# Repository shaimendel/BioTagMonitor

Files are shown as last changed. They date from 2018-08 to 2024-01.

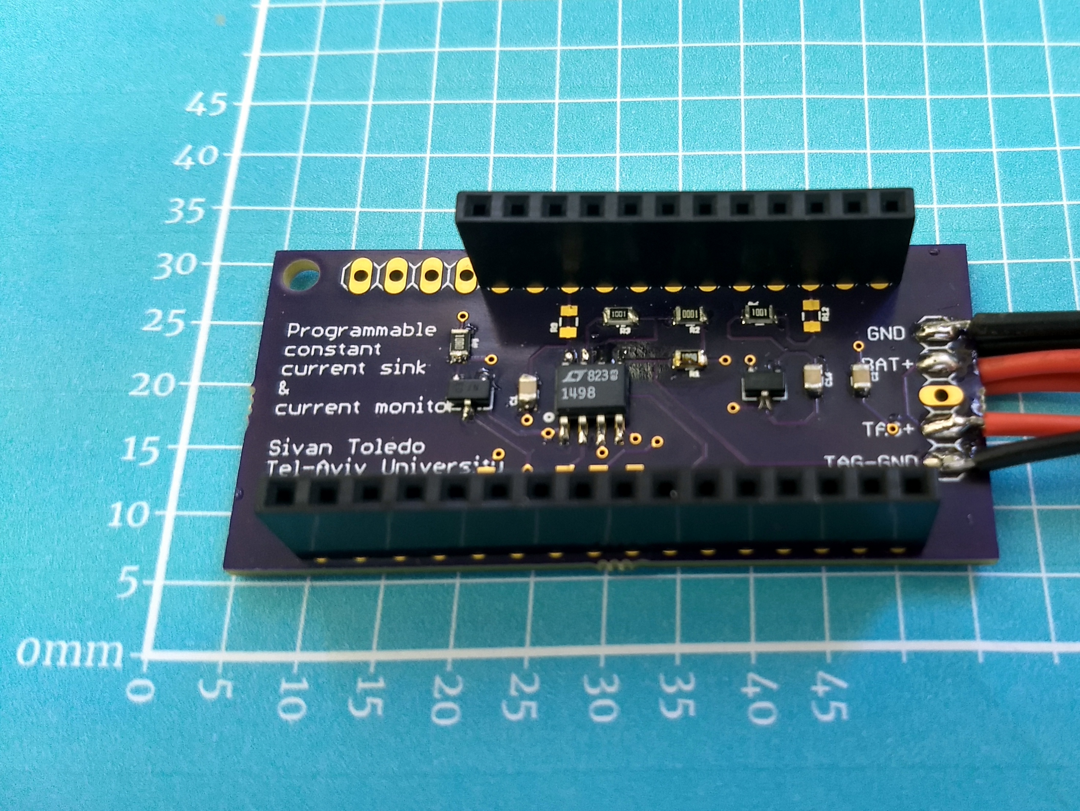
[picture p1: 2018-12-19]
Paper/2018-11-28 09.57.43.jpg

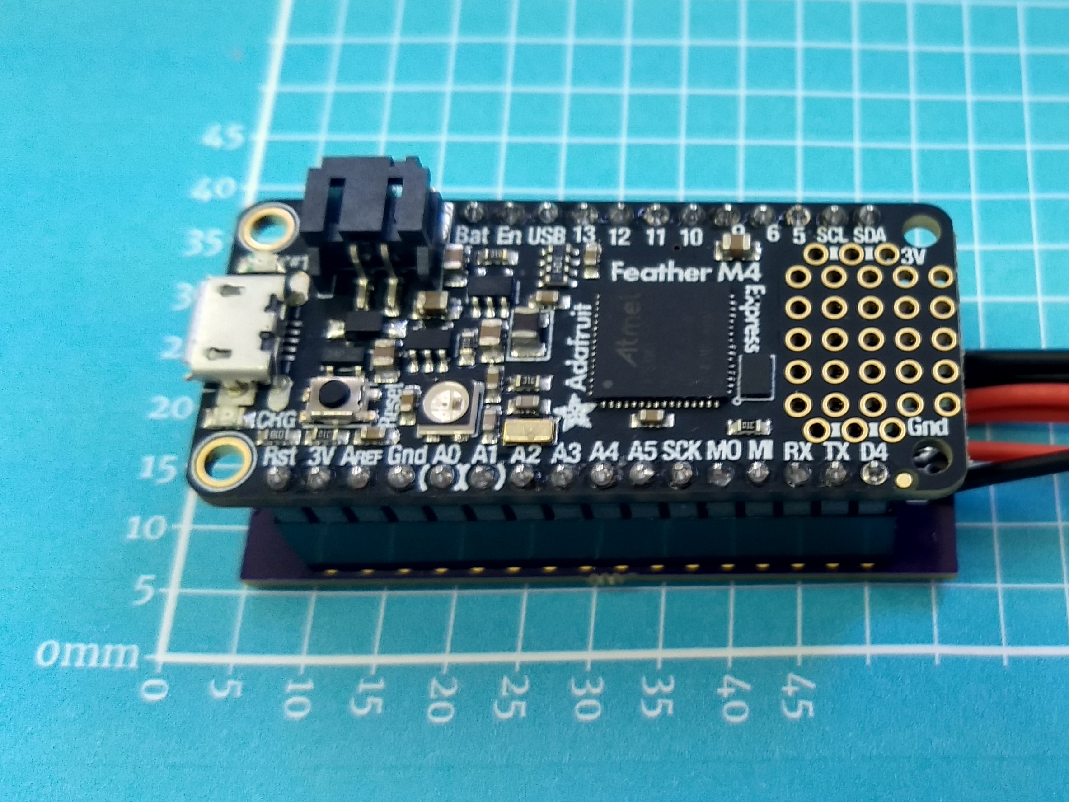
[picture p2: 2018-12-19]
Paper/2018-11-28 09.58.49.jpg

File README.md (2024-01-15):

# Software, Firmware, and Hardware for a Battery Characterization System
Biological tags are very popular in the field of animal behaviour research.
These tags developers have to deal with numerous problems, both in hardware and software.
One of the problems is to choose the correct battery to put within the tag itself: the battery should be lightweight, to last long, to cope with different weather conditions, etc.
Until now, the setup and procedure of comparing different batteries performance included:
- A mocked tag: A dedicated circuit that used the battery in the same way the tag does
- The battery itself
- Scope and other expensive equipment to measure the voltage and current along time

This procedure is long, expensive and uncomfortable.
This project concentrates on biological tags that are put on birds, these tags send a short pulse (8-10ms) of location every ~1 second.

## Goal
This project implements an arduino and PC software that communicate with each other and make the entire procedure very easy, cheap and quick.
The project contains:
- Various arduino softwares for different needs
- A PC software (C#) that operates the arduino and logs the measurements
- A PC software (Python) for visualization

## Content

### Visualization
- createData.py: Creates a mock log file with mocked measurements
- visualizeData.py: Measurements visualization utility

### Measure
The C# project that operates the arduino, both for tag simulation and also with real tags.
In order to compile Measure.csproj to mono: 
- cd to Measure.csproj folder
- xbuild /p:TargetFrameworkVersion="v4.5"

#### AutoMeasureGraphMin
Arduino software to measure bio tags.
This software communicates with the PC software and sends the measurements to it.
Supports 2 modes:
- Simulation: The sofware simulates tag behaviour and measures the battery performance in pulses along time
- Real tag: Measurement of real tag pulses. This mode contains a pulse identification algorithm, becuase the tag itself produces the pulses.

#### AutoMeasureGraphStart
Arduino software to measure bio tags in a situation the tag fails to start.
This software records measurements as soon as it identifies an activity in the tag and sends it to the PC software

#### PCB
Circuit and printed-circut board design for the add-on analog board. These are Eagle 6.6 files. The "relabeled" schmatics is cleaned up a bit for clarity. It also does not include 0-Ohm resistors and jumper traces that are included in the original design to allow patching the board. 

#### Simulation
LTSpice simulation model for the analysis of the reservoir cap and its limiter resistor.

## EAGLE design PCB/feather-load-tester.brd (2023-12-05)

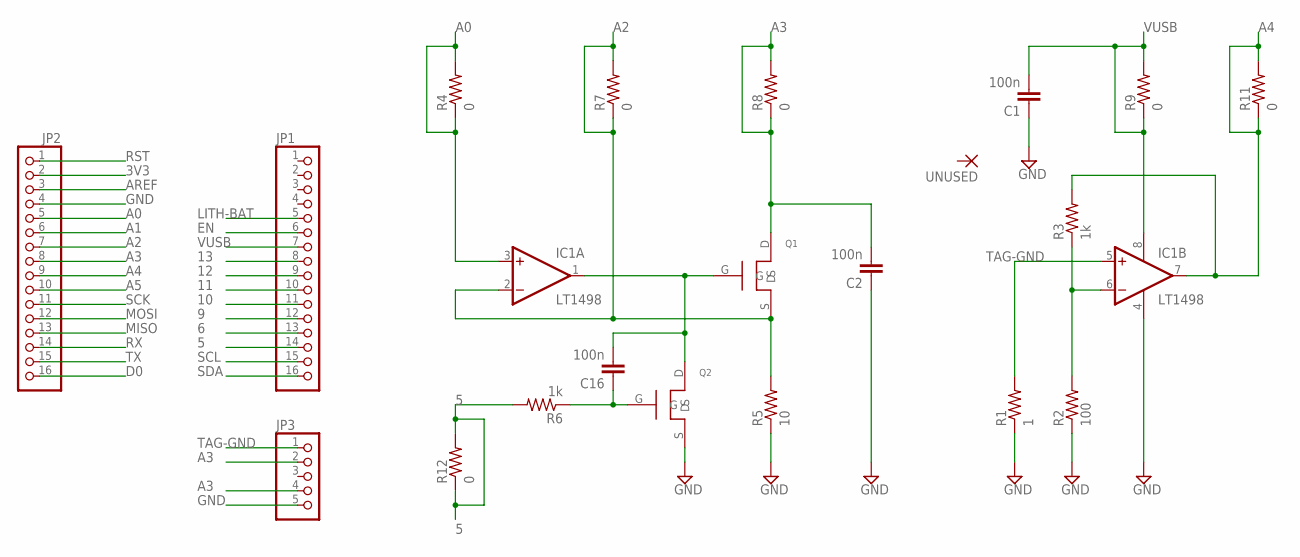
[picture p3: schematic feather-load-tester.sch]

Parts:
C1, C2, C16: 100n; 0805-CAP
IC1: LT1498; SO08
JP1, JP2: PINHD-1X16; 1X16
JP3: PINHD-1X5; 1X05
Q1, Q2: NMOSFET_SC59; SC59
R1: 1; 0805
R2: 100; 0805
R3, R6: 1k; 0805
R4, R7, R8, R9, R11, R12: 0; 0805
R5: 10; 0805
UNUSED: SMD2; SMD1,27-2,54

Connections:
3V3: JP2.2
5: JP1.14, R6.2, R12.1, R12.2
6: JP1.13
9: JP1.12
10: JP1.11
11: JP1.10
12: JP1.9
13: JP1.8
A0: IC1.3 (+IN), JP2.5, R4.1, R4.2
A1: JP2.6
A2: IC1.2 (-IN), JP2.7, Q1.S, R5.2, R7.1, R7.2
A3: C2.2, JP2.8, JP3.2, JP3.4, Q1.D, R8.1, R8.2
A4: IC1.7 (OUT), JP2.9, R3.2, R11.1, R11.2
A5: JP2.10
AREF: JP2.3
D0: JP2.16
EN: JP1.6
GND: C1.1, C2.1, IC1.4 (V-), JP2.4, JP3.5, Q2.S, R1.1, R2.1, R5.1
LITH-BAT: JP1.5
MISO: JP2.13
MOSI: JP2.12
unnamed: IC1.6 (-IN), R2.2, R3.1
unnamed: C16.1, Q2.G, R6.1
unnamed: C16.2, IC1.1 (OUT), Q1.G, Q2.D
RST: JP2.1
RX: JP2.14
SCK: JP2.11
SCL: JP1.15
SDA: JP1.16
TAG-GND: IC1.5 (+IN), JP3.1, R1.2
TX: JP2.15
VUSB: C1.2, IC1.8 (V+), JP1.7, R9.1, R9.2

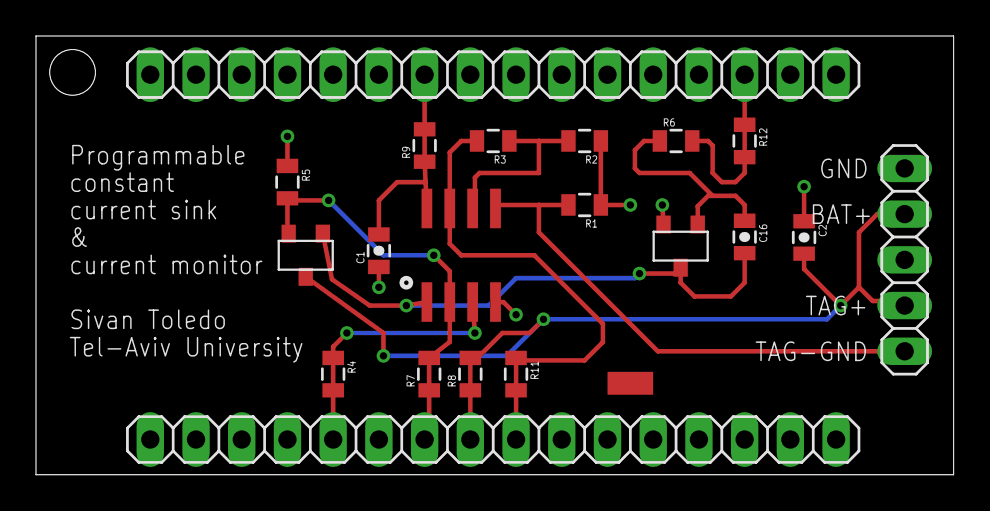
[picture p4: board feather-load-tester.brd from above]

Board: 2 copper layers, 51.0 x 24.4 mm, 21 parts (0 on the bottom side), 11 nets.

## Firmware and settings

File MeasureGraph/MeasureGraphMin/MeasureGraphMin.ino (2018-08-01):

const int digital_pin = PC3;
const int analogPins[2] = { PA1, PA2 };
const int analogCount = sizeof(analogPins)/sizeof(analogPins[0]);
const int analog_output_pin = PA4;

// the setup function runs once when you press reset or power the board
void setup() {
  // initialize digital pin LED_BUILTIN as an output.
  pinMode(analog_output_pin, PWM);
  pinMode(digital_pin, OUTPUT);
  uint8_t i;
  for (i = 0; i < analogCount; i++)
  {
    pinMode(analogPins[i], INPUT_ANALOG);
  }

  setVoltageRaw(analog_output_pin, 0);
  setDigitalVoltage(digital_pin, HIGH);
  
  // Open serial communications and wait for port to open:
  Serial.begin(9600);
  while (!Serial) {
    ; // wait for serial port to connect. Needed for native USB port only
  }

  //Serial.println("\n\nBeginning test:");
}

// the loop function runs over and over again forever
volatile long dac_voltage = 372;
volatile long pulse_length = 8;

void loop() {
  if (Serial.available() <= 0)
    return;

  String dac_voltage_string = Serial.readStringUntil('\n');
  String pulse_length_string = Serial.readStringUntil('\n');
  dac_voltage = atoi(dac_voltage_string.c_str());
  pulse_length = atoi(pulse_length_string.c_str());
//  Serial.print("Got voltage: ");
//  Serial.print(dac_voltage_string.c_str());
//  Serial.print(", pulse: ");
//  Serial.println(pulse_length_string.c_str());
//  Serial.println("---------------------------");
  
  setDigitalVoltage(digital_pin, LOW);
  setVoltageRaw(analog_output_pin, dac_voltage);

  unsigned long currentMillis = millis();
  float a2_in_pulse = getVoltage(PA2); //Battery Voltage
  float a1_in_pulse = getVoltage(PA1); //Current

  while (millis() - currentMillis < pulse_length) {
    float tmp = getVoltage(PA2);
    if (tmp < a2_in_pulse) {
      a2_in_pulse = tmp;
    }

    tmp = getVoltage(PA1);
    if (tmp > a1_in_pulse) {
      a1_in_pulse = tmp;
    }
  }
  
  setDigitalVoltage(digital_pin, HIGH);
  setVoltageRaw(analog_output_pin, 0);
  
  Serial.print(a2_in_pulse, 5);
  Serial.print(",");
  Serial.println(a1_in_pulse, 5);
}

void setDigitalVoltage(int pin, int value) {
//  Serial.print("Set digital voltage for pin ");
//  Serial.print(pin);
//  Serial.print(": ");
//  Serial.print(value);
  digitalWrite(pin, value);
//  Serial.println();
}

void setVoltageRaw(int pin, int value) {
  analogWrite(pin, 3.3*(value/255));
}

void setVoltage(int pin, float value) {
  Serial.print("Set analog voltage for pin ");
  Serial.print(pin);
  Serial.print(": ");
  Serial.print(value);
  Serial.println("V");
  //pwnWrite(int(65535 * value / 3.3))
  analogWrite(pin, int(255 * value / 3.3));
}

void printVoltage2(int pin) {
  Serial.print("Read voltage 1 for pin ");
  Serial.print(pin);
  Serial.print(": ");
  Serial.println(analogRead(pin)*(5.0 / 1023.0));
}

void printVoltage(int pin) {
    float       vbatLSB        = 0.80566F;  // mV per LSB
    int   vbati = 0;    // Raw integer value
    vbati = analogRead(pin);
    Serial.print("Read voltage 2 for pin ");
    Serial.print(pin);
    Serial.print(": ");

  // Display the value in volts (based on 3.3V VRef)
    float vbatf = ((float)vbati * vbatLSB);
    Serial.print(vbatf/1000, 2);
    Serial.println("V");
}

float getVoltage(int pin) {
  float       vbatLSB        = 0.80566F;  // mV per LSB
    int   vbati = 0;    // Raw integer value
    vbati = analogRead(pin);
  // Display the value in volts (based on 3.3V VRef)
    float vbatf = ((float)vbati * vbatLSB);
    //Serial.print(vbatf/1000, 2);
    //Serial.println("V");
    return vbatf/1000;
}

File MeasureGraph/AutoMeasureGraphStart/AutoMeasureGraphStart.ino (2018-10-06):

#include "vector.h"
#include "real_tag.h"
#include "arch.h"
#include "utils.h"

#define CALIBRATION_SAMPLES_AMOUNT 20
#define CURRENT_MULTIPLIER_THRESHOLD 1.5
#define RECORDING_SECONDS 4

vector pulse_samples_vector;
float rest_amper_avg = 0;
bool pulse_started = false;
unsigned long pulse_start = 0;
bool finished = false;

void setup() {
  pinMode(SHUTDOWN_PIN, OUTPUT);
  specific_board_init();

  pinMode(DAC_PIN, OUTPUT);
  setDigitalVoltage(SHUTDOWN_PIN, HIGH);
  vector_init(&pulse_samples_vector);

  // Open serial communications and wait for port to open:
  Serial.begin(14400);
  while (!Serial || Serial.available() <= 0) {
      ; // wait for serial port to connect. Needed for native USB port only
  }

  for (int i = 0; i < CALIBRATION_SAMPLES_AMOUNT; i++) {
    rest_amper_avg += getVoltage(TAG_LOAD_CURRENT); //Current
  }

  rest_amper_avg /= CALIBRATION_SAMPLES_AMOUNT;
}

bool has_pulse_started() {
  float current = getVoltage(TAG_LOAD_CURRENT);
  if (current > rest_amper_avg * CURRENT_MULTIPLIER_THRESHOLD) {
    return true;
  }

  return false;
}

unsigned long last_pulse = 0;

void loop() {
  if (finished) {
    return;
  }
  if (!pulse_started) {
    pulse_started = has_pulse_started();
    pulse_start = millis();
    last_pulse = pulse_start - 1;
    return;
  }

  unsigned long now = millis();

  if (now - last_pulse < 1){
    return;
  }

  float current_voltage = getVoltage(BATTERY_VOLTAGE); //Battery Voltage
  float current_amper = getVoltage(TAG_LOAD_CURRENT); //Current

  addPulseToVector(&pulse_samples_vector, current_voltage, current_amper, now - pulse_start);
  last_pulse = now;

  if (now - pulse_start > RECORDING_SECONDS*1000) {
    finished = true;
    Serial.print(0);
    Serial.print(",");
    Serial.print(0);
    Serial.print(",");
    Serial.print(0);
    Serial.print(",");
    Serial.print(0);
    Serial.print(",");
    vector_serialize(&pulse_samples_vector);
    Serial.println();
  }
}

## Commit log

2018-07-07 Don't start the simulation task before the go button is pressed
2018-08-25 Added sampling during pulse. Added voltage sampling during rest
2018-09-01 Better handle samples before pulse
2018-09-29 Fixed recording of samples before pulse
    [real_rag.cpp]
2018-10-06 visualizeData.py: Added os flag + if the log contains a single sample than show it
2018-11-07 Added different y axis to current Divided current by 11
2018-11-21 Added the option to skip "potential bad pulses" (with the polarization symptom)
    [simulated_tag.cpp]
2023-12-05 added PCB files
    [feather-load-tester-relabeled.sch, feather-load-tester.brd, feather-load-tester.sch]
2023-12-05 description of PCB directory

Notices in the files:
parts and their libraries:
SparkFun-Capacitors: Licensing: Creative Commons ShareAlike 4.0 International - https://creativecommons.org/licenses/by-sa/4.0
